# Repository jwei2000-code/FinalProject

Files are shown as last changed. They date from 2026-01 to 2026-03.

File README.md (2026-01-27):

# FinalProject
# The "Deep Work Halo"

## 1. Overview
The Deep Work Halo is a privacy-focused workspace monitor designed to help users maintain and signal a "Flow State" without distraction. It consists of a discreet wearable that analyzes head stability to detect focus levels and wirelessly updates a desktop analog gauge. This gauge visually communicates the user's cognitive state to colleagues, acting as an automatic "Do Not Disturb" signal when deep work is achieved.

## 2. Visual Concept & Physical Design

### The Sensing Device (The "Smart Ear-Cuff")
* **Form Factor:** It uses a C-bridge design. One part sits behind the ear (battery/logic), and a smaller part sits inside/front of the ear (sensor), connected by a flexible silicone bridge.
* **Physical Features:** Completely screen-less and light-less to prevent user distraction. It houses the internal electronics and battery, featuring only a single pinhole reset button on the back.

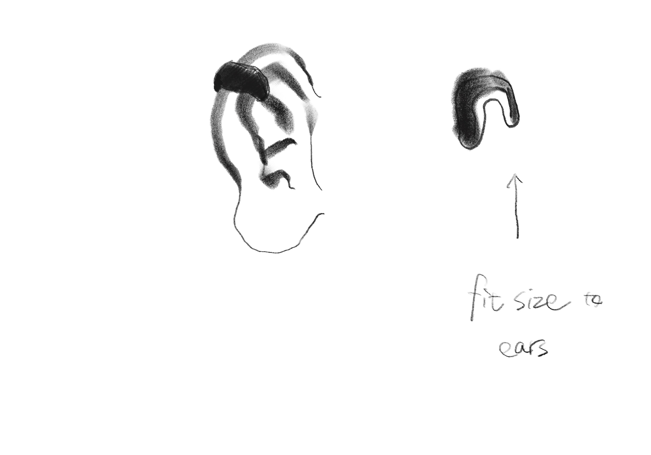
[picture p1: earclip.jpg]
Sensing Device Ear Hook


### The Display Device ("The Flow Monolith")
* **Form Factor:** A minimalist, solid cube or rectangular prism (approx. 6cm x 6cm).
* **Materials:**
    * **Inner Core:** Matte black internal chassis.
    * **Outer Shell:** Thick, frosted clear acrylic (or smoked polycarbonate) acting as a massive light diffuser.
* **The Interface (Visual):**
    * **Screen:** A hidden LED Dot Matrix (8x8 or 16x16 grids) or a low-res OLED behind the acrylic face.
    * **Typography:** Uses a strict **Bitmap / Pixel font** for a retro-futuristic aesthetic.
    * **Function:** Displays the current time by default. When focus is detected, it transitions to a "Focus Score" (0-100) or a pixelated status icon.
* **The Interface (Atmosphere):**
    * **Breathing Light:** Buried RGB LEDs illuminate the entire acrylic block from within.
    * **Behavior:**
        * *Standby:* Off or faint white (Clock Mode).
        * *Flow State:* Gently pulses in warm Amber/Red (Do Not Disturb signal).
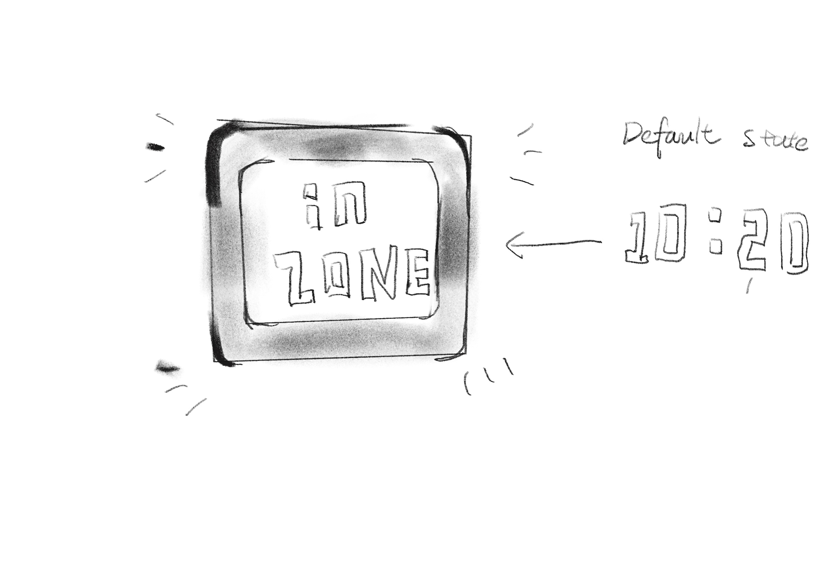
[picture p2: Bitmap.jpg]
Display Device Monolith


## 3. Technical Architecture

### Sensors & Inputs (The "Sense")
* **Device:** 6-Axis IMU (Inertial Measurement Unit).
* **Function:** Captures accelerometer and gyroscope data to track head micro-movements.
* **Logic:** A TinyML model running locally on the wearable classifies data into states (e.g., Focused vs. Fidgeting vs. Talking).

### Interface & Outputs (The "Feedback")
* **Stepper Motor:** Provides non-intrusive, peripheral visual feedback on focus depth.
* **RGB LED Ring:** Provides social signaling (Red/Amber = DND) to the external environment.

### Connectivity & Power
* **Wireless Protocol:** BLE (Bluetooth Low Energy) for efficient communication between the Wearable (Server) and Desktop Gauge (Client).
* **Power Source:**
    * *Wearable:* CR2032 Coin Cell (optimized for deep sleep).
    * *Desktop:* LiPo battery with USB-C charging.

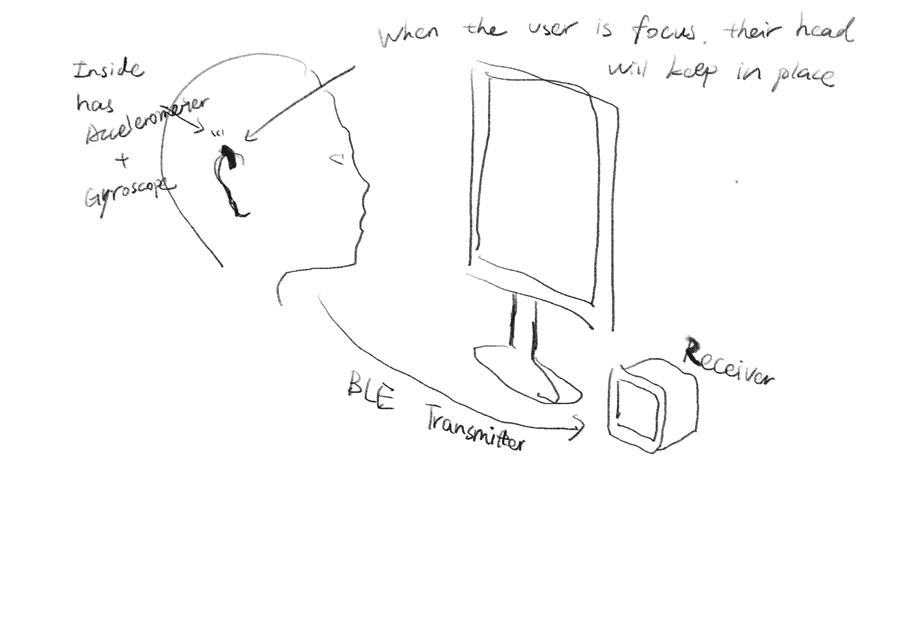
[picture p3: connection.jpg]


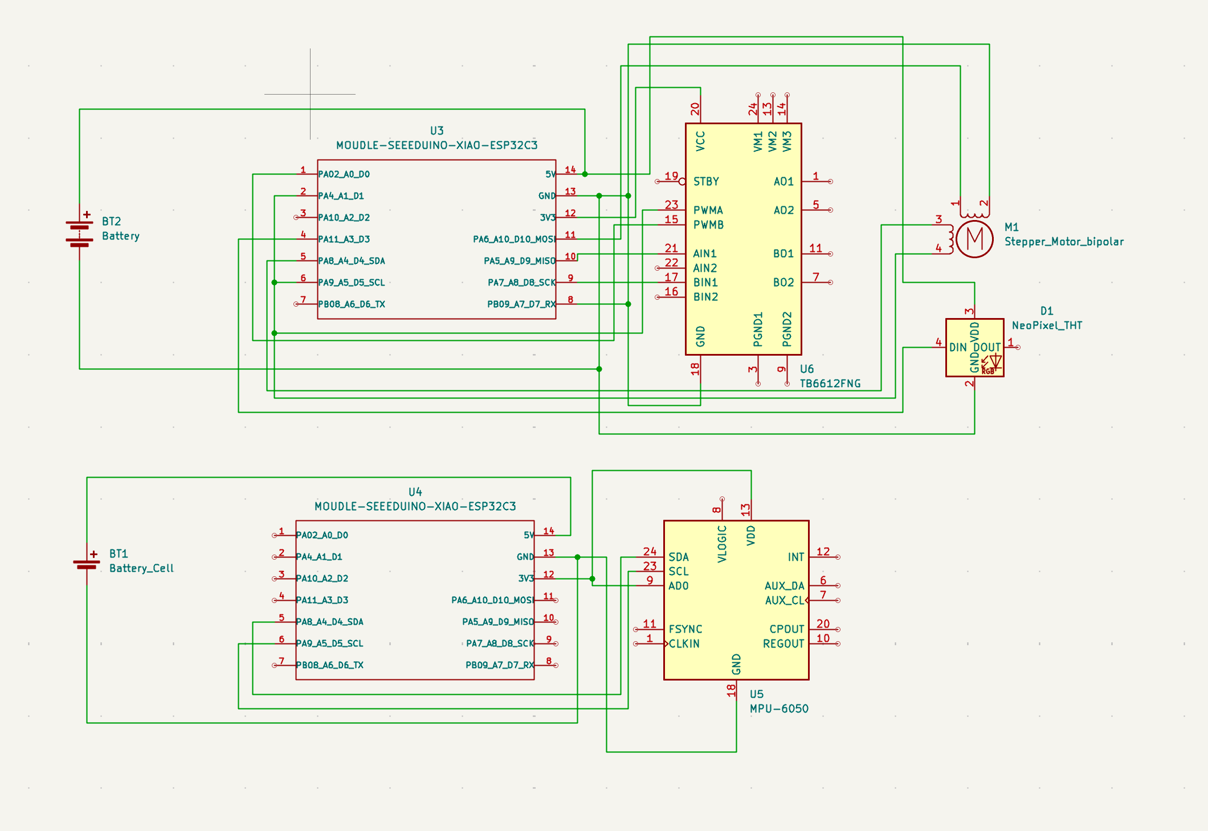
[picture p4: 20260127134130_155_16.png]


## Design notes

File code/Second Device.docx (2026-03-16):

The script uses a SwitecX25 stepper motor to physically move a needle to an "In Zone" position when my focus level hits a threshold of 70, giving me that non-intrusive peripheral feedback I wanted. At the same time, it controls a 7-bit WS2812B LED ring on pin D9 to create a "breathing" amber light effect, which serves as a social signal to tell others I’m in a deep work state. In its default state, the motor stays at a "Ready" position, and the LEDs remain off to keep my environment distraction-free.

One Photo of Functional Breadboard, Perfboard, or PCB

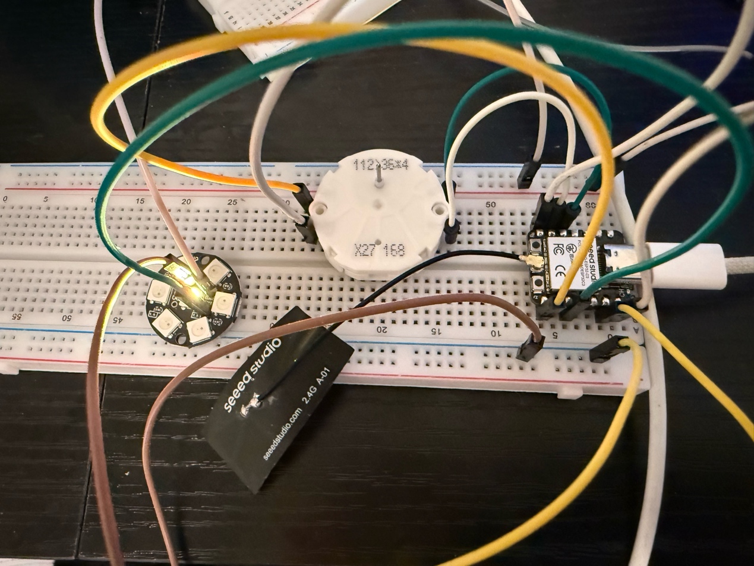
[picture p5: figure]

Two screenshots of CAD Model

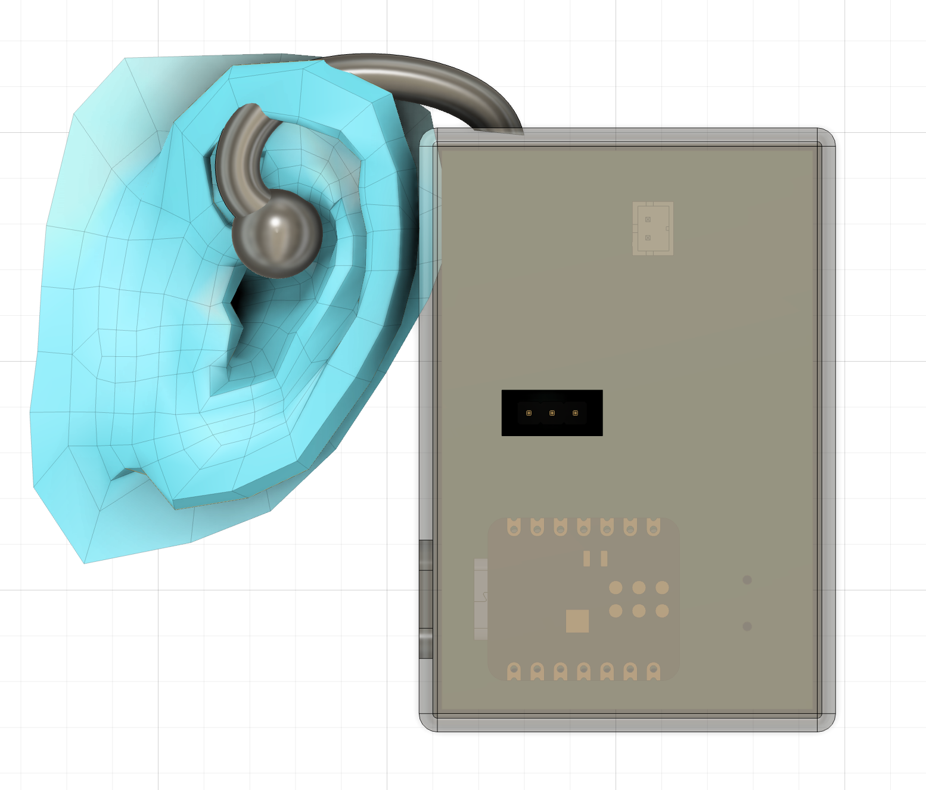
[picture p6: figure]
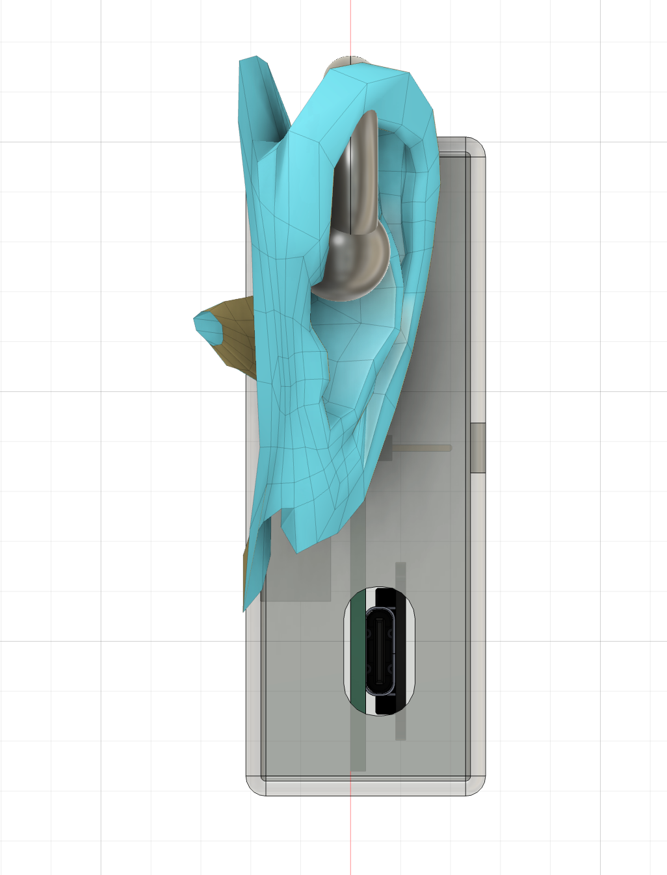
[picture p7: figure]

Link to code in Github

https://github.com/jwei2000-code/FinalProject/tree/main/code/display

#include <SwitecX25.h>

#include <Adafruit_NeoPixel.h>

#include <BLEDevice.h>

// --- Configuration ---

#define LED_PIN D9

#define NUM_LEDS 7

#define STEPS 945

#define IN_ZONE_POS 800

#define READY_POS 100

// IMPORTANT: use ESP32 GPIO numbers that you wired through a driver (ULN2003/transistors)

// XIAO ESP32C3 example pins (change to your actual wiring)

#define COIL1 4

#define COIL2 5

#define COIL3 6

#define COIL4 7

SwitecX25 motor(STEPS, COIL1, COIL2, COIL3, COIL4);

Adafruit_NeoPixel ring(NUM_LEDS, LED_PIN, NEO_GRB + NEO_KHZ800);

int focusLevel = 0;

void setup() {

Serial.begin(115200);

ring.begin();

ring.setBrightness(50);

ring.show();

motor.setPosition(READY_POS);

}

void loop() {

motor.update();

if (focusLevel >= 70) {

motor.setPosition(IN_ZONE_POS);

pulseLEDs(255, 120, 0);

} else {

motor.setPosition(READY_POS);

ring.clear();

ring.show();

}

}

void pulseLEDs(uint8_t r, uint8_t g, uint8_t b) {

float s = sin(millis() / 500.0f);

uint8_t brightness = (uint8_t)((s + 1.0f) * 127.0f);

for (int i = 0; i < NUM_LEDS; i++) {

ring.setPixelColor(i, ring.Color((r * brightness) / 255, (g * brightness) / 255, (b * brightness) / 255));

}

ring.show();

}

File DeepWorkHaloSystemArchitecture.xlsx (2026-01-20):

Wearable Sensing Device (Edge Processing) |  | Desktop Display Device (Output Controller)
Power: CR2032 Coin Cell (Deep Sleep Optimized) |  | Power: LiPo Battery / USB-C
[ 1. DATA COLLECTION ]6-Axis IMU Sensor(Accelerometer + Gyroscope)↓ |  | [ 4. RECEIVE & LOGIC ]BLE Receiver Module↓Main MCU (e.g., ESP32)(Interprets State, manages animations)↓
[ 2. TINYML INFERENCE ]Onboard Low-Power MCU(Runs Pre-trained Model: Classifies Motion vs. Stillness)↓ | → BLE → | [ 5. DUAL OUTPUT DRIVERS ]Does User = Focused?↙️ ↘️
[ 3. STATE TRANSMISSION ]BLE Transmitter(Sends simplified "State Packet" e.g., 0=Idle, 1=Flow) |  | [Output A: Info] [Output B: Mood]LED Matrix Driver PWM LED Driver↓ ↓Bitmap Display Acrylic Aura LEDs(Clock fades to Icon) ("Breathing" Light)

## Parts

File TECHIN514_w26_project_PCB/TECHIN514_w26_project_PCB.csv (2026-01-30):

Reference | Qty | Value | DNP | Exclude from BOM | Exclude from Board | Footprint | Datasheet
C1 | 1 | 0.1µF |  |  |  | Capacitor_SMD:C_0603_1608Metric_Pad1.08x0.95mm_HandSolder | ~
C2 | 1 | 4.7µF |  |  |  | Capacitor_SMD:C_0603_1608Metric_Pad1.08x0.95mm_HandSolder | ~
C3 | 1 | 0.47µF |  |  |  | Capacitor_SMD:C_0603_1608Metric_Pad1.08x0.95mm_HandSolder | ~
D1 | 1 | LED |  |  |  | LED_SMD:LED_0603_1608Metric_Pad1.05x0.95mm_HandSolder | ~
J1 | 1 | Conn_01x04_Pin |  |  |  | Connector_PinSocket_2.54mm:PinSocket_1x04_P2.54mm_Vertical | ~
R1,R2,R3 | 3 | 10kΩ |  |  |  | Resistor_SMD:R_0603_1608Metric_Pad0.98x0.95mm_HandSolder | ~
R4 | 1 | 0.45µF |  |  |  | Resistor_SMD:R_0603_1608Metric_Pad0.98x0.95mm_HandSolder | ~
R5 | 1 | 330kΩ |  |  |  | Resistor_SMD:R_0603_1608Metric_Pad0.98x0.95mm_HandSolder | ~
R6 | 1 | 698kΩ |  |  |  | Resistor_SMD:R_0603_1608Metric_Pad0.98x0.95mm_HandSolder | ~
R7 | 1 | 340kΩ |  |  |  | Resistor_SMD:R_0603_1608Metric_Pad0.98x0.95mm_HandSolder | ~
R8 | 1 | 10KΩ |  |  |  | Resistor_SMD:R_0603_1608Metric_Pad0.98x0.95mm_HandSolder | ~
U1 | 1 | LTR-390UV-01 |  |  |  | LTR_390UV_01_footprints:SMD6_LTR-390UV-01_LTO | LTR-390UV-01
U2 | 1 | ADP3331ARTZ-REEL7 |  |  |  | ADP3331ARTZ_REEL7_footprints:SOT95P280X145-6N

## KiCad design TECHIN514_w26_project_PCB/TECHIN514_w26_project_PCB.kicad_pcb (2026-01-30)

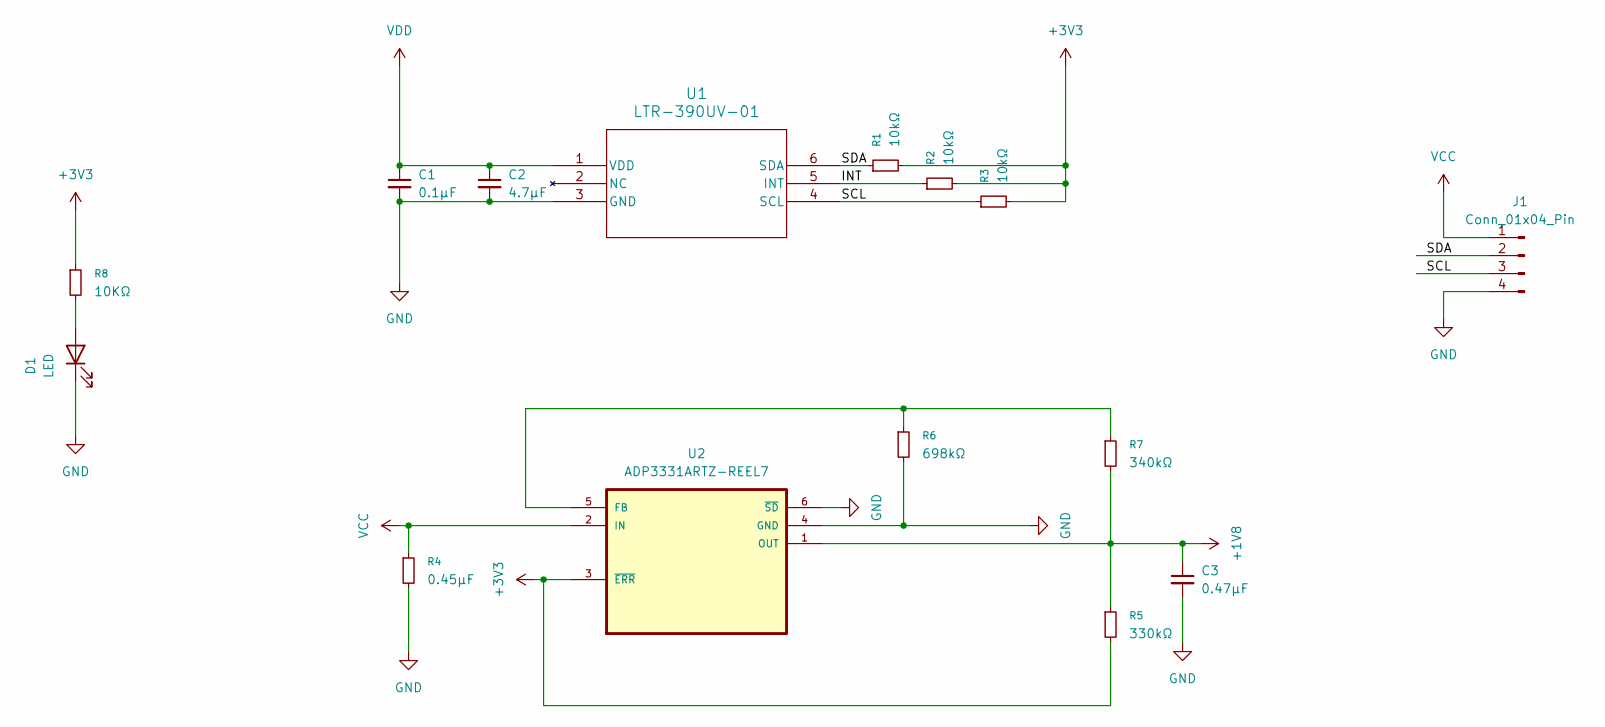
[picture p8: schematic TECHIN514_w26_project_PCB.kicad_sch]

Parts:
C1: 0.1µF; C_0603_1608Metric_Pad1.08x0.95mm_HandSolder
C2: 4.7µF; C_0603_1608Metric_Pad1.08x0.95mm_HandSolder
C3: 0.47µF; C_0603_1608Metric_Pad1.08x0.95mm_HandSolder
D1: LED; LED_0603_1608Metric_Pad1.05x0.95mm_HandSolder
J1: Conn_01x04_Pin; PinSocket_1x04_P2.54mm_Vertical
R1, R2, R3: 10kΩ; R_0603_1608Metric_Pad0.98x0.95mm_HandSolder
R4: 0.45µF; R_0603_1608Metric_Pad0.98x0.95mm_HandSolder
R5: 330kΩ; R_0603_1608Metric_Pad0.98x0.95mm_HandSolder
R6: 698kΩ; R_0603_1608Metric_Pad0.98x0.95mm_HandSolder
R7: 340kΩ; R_0603_1608Metric_Pad0.98x0.95mm_HandSolder
R8: 10KΩ; R_0603_1608Metric_Pad0.98x0.95mm_HandSolder
U1: LTR-390UV-01; SMD6_LTR-390UV-01_LTO
U2: ADP3331ARTZ-REEL7; SOT95P280X145-6N

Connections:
+1V8: C3.1, R5.1, R7.2, U2.1 (OUT)
+3V3: R1.2, R2.2, R3.2, R5.2, R8.1, U2.3 (~ERR)
/INT: R2.1, U1.5 (INT)
/SCL: J1.3, R3.1, U1.4 (SCL)
/SDA: J1.2, R1.1, U1.6 (SDA)
GND: C1.2, C2.2, C3.2, D1.1 (K), J1.4, R4.2, R6.2, U1.3 (GND), U2.4 (GND), U2.6 (~SD)
unnamed: D1.2 (A), R8.2
unnamed: R6.1, R7.1, U2.5 (FB)
VCC: J1.1, R4.1, U2.2 (IN)
VDD: C1.1, C2.1, U1.1 (VDD)

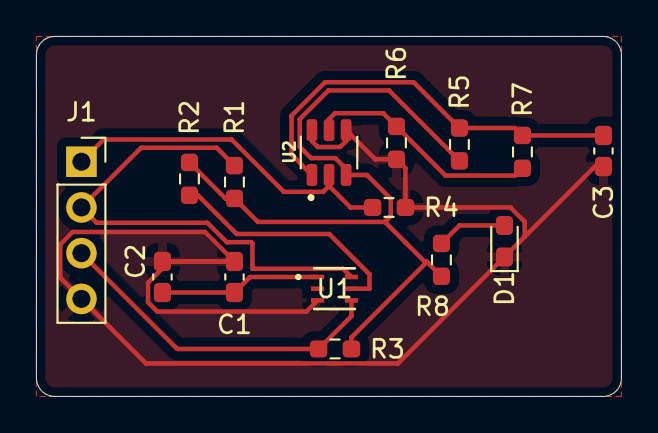
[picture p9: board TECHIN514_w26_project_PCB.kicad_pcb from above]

Board: 2 copper layers, 32.5 x 20.0 mm, 15 parts (0 on the bottom side), 10 nets.

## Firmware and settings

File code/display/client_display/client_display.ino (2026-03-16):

#include <Arduino.h>
#include <BLEDevice.h>
#include <BLEUtils.h>
#include <BLEScan.h>
#include <BLEAdvertisedDevice.h>
#include <SwitecX25.h>
#include <Adafruit_NeoPixel.h>
#include <math.h>

static BLEUUID serviceUUID("30e2772d-6dda-4baa-a391-ec111e9b1a84");
static BLEUUID    charUUID("0e26f354-8aae-46ea-9dce-195ce2227fad");

#define STEPS           630
#define NOT_FOCUSED_POS 30
#define FOCUSED_POS     600
#define COIL1 4
#define COIL2 5
#define COIL3 6
#define COIL4 7
#define LED_PIN  D9
#define NUM_LEDS 7

SwitecX25 motor(STEPS, COIL1, COIL2, COIL4, COIL3);
Adafruit_NeoPixel ring(NUM_LEDS, LED_PIN, NEO_GRB + NEO_KHZ800);

static boolean doConnect = false;
static boolean connected = false;
static BLERemoteCharacteristic* pRemoteCharacteristic;
static BLEAdvertisedDevice* myDevice;
static BLEScan* pBLEScan;

volatile int focusScore = 0;
unsigned long lastLEDUpdate = 0;
unsigned long lastScanStart = 0;
int lastMotorPos = NOT_FOCUSED_POS;

inline int clampPos(int p) { return constrain(p, 0, STEPS - 1); }

void pulseLEDs(uint8_t r, uint8_t g, uint8_t b) {
  float s = sin(millis() / 500.0f);
  uint8_t brightness = (uint8_t)((s + 1.0f) * 127.0f);
  for (int i = 0; i < NUM_LEDS; i++)
    ring.setPixelColor(i, ring.Color((r*brightness)/255, (g*brightness)/255, (b*brightness)/255));
  ring.show();
}

void solidLEDs(uint8_t r, uint8_t g, uint8_t b) {
  for (int i = 0; i < NUM_LEDS; i++)
    ring.setPixelColor(i, ring.Color(r, g, b));
  ring.show();
}

static void notifyCallback(BLERemoteCharacteristic* p, uint8_t* pData, size_t length, bool isNotify) {
  focusScore = String((char*)pData).substring(0, length).toInt();
}

class MyClientCallback : public BLEClientCallbacks {
  void onConnect(BLEClient* p) {}
  void onDisconnect(BLEClient* p) {
    connected = false;
    focusScore = 0;
  }
};

bool connectToServer() {
  BLEClient* pClient = BLEDevice::createClient();
  pClient->setClientCallbacks(new MyClientCallback());
  pClient->connect(myDevice);
  pClient->setMTU(517);
  BLERemoteService* pRemoteService = pClient->getService(serviceUUID);
  if (!pRemoteService) { pClient->disconnect(); return false; }
  pRemoteCharacteristic = pRemoteService->getCharacteristic(charUUID);
  if (!pRemoteCharacteristic) { pClient->disconnect(); return false; }
  if (pRemoteCharacteristic->canNotify())
    pRemoteCharacteristic->registerForNotify(notifyCallback);
  connected = true;
  return true;
}

class MyAdvertisedDeviceCallbacks : public BLEAdvertisedDeviceCallbacks {
  void onResult(BLEAdvertisedDevice advertisedDevice) {
    if (advertisedDevice.haveServiceUUID() && advertisedDevice.isAdvertisingService(serviceUUID)) {
      pBLEScan->stop();
      myDevice = new BLEAdvertisedDevice(advertisedDevice);
      doConnect = true;
    }
  }
};

void startScan() {
  pBLEScan->clearResults();
  pBLEScan->start(5, false);
  lastScanStart = millis();
}

void setup() {
  Serial.begin(115200);
  ring.begin(); ring.setBrightness(50); ring.clear(); ring.show();

  motor.setPosition(0);
  for (int i = 0; i < 6000; i++) { motor.update(); delayMicroseconds(800); }
  motor.setPosition(clampPos(NOT_FOCUSED_POS));
  for (int i = 0; i < 3000; i++) { motor.update(); delayMicroseconds(800); }

  BLEDevice::init("");
  pBLEScan = BLEDevice::getScan();
  pBLEScan->setAdvertisedDeviceCallbacks(new MyAdvertisedDeviceCallbacks());
  pBLEScan->setInterval(1349);
  pBLEScan->setWindow(449);
  pBLEScan->setActiveScan(true);
  startScan();
}

void loop() {
  motor.update();

  unsigned long now = millis();

  if (doConnect) {
    doConnect = false;
    if (connectToServer()) {
      Serial.println("Connected!");
    } else {
      Serial.println("Failed, retrying...");
      startScan();
    }
  }

  if (!connected && (now - lastScanStart >= 6000)) {
    startScan();
  }

  int targetPos = (focusScore >= 30) ? clampPos(FOCUSED_POS) : clampPos(NOT_FOCUSED_POS);
  if (targetPos != lastMotorPos) {
    motor.setPosition(targetPos);
    lastMotorPos = targetPos;
  }

  if (now - lastLEDUpdate >= 30) {
    lastLEDUpdate = now;
    if (focusScore >= 30) pulseLEDs(0, 255, 0);
    else solidLEDs(0, 0, 255);
  }
}

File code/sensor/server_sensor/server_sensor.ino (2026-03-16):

#include <Arduino.h>
#include <Wire.h>
#include <BLEDevice.h>
#include <BLEServer.h>
#include <BLEUtils.h>
#include <BLE2902.h>

// ── BLE UUIDs ──────────────────────────────────────────────────
#define SERVICE_UUID        "30e2772d-6dda-4baa-a391-ec111e9b1a84"
#define CHARACTERISTIC_UUID "0e26f354-8aae-46ea-9dce-195ce2227fad"

// ── MPU6500 ────────────────────────────────────────────────────
#define MPU_ADDR 0x68

// ── Moving average filter ──────────────────────────────────────
const int FILTER_SIZE = 10;
float gyroReadings[FILTER_SIZE] = {0};
int filterIndex = 0;
float filterSum = 0.0;

// ── BLE globals ────────────────────────────────────────────────
BLEServer* pServer = NULL;
BLECharacteristic* pCharacteristic = NULL;
bool deviceConnected = false;
bool oldDeviceConnected = false;

class MyServerCallbacks : public BLEServerCallbacks {
    void onConnect(BLEServer* pServer)    { deviceConnected = true;  Serial.println("Client connected!"); }
    void onDisconnect(BLEServer* pServer) { deviceConnected = false; Serial.println("Client disconnected!"); }
};

// ── MPU helpers (exactly from your working code) ───────────────
void mpuWrite(byte reg, byte val) {
  Wire.beginTransmission(MPU_ADDR);
  Wire.write(reg);
  Wire.write(val);
  Wire.endTransmission(true);
}

byte mpuRead(byte reg) {
  Wire.beginTransmission(MPU_ADDR);
  Wire.write(reg);
  Wire.endTransmission(false);
  Wire.requestFrom(MPU_ADDR, 1);
  return Wire.available() ? Wire.read() : 0xFF;
}

// ── Moving average DSP ─────────────────────────────────────────
float movingAverage(float newVal) {
  filterSum -= gyroReadings[filterIndex];
  gyroReadings[filterIndex] = newVal;
  filterSum += newVal;
  filterIndex = (filterIndex + 1) % FILTER_SIZE;
  return filterSum / FILTER_SIZE;
}

// ── Map smoothed gyro magnitude to focus score 0-100 ──────────
int calcFocusScore(float smoothedMag) {
  const float MAX_MAG = 150.0;
  return (int)(constrain(smoothedMag / MAX_MAG, 0.0, 1.0) * 100.0);
}

void setup() {
  Serial.begin(115200);
  delay(1000);  // 
  
  // ── MPU init (same as your working code) ────────────────────
  Wire.begin(6, 7);
  Wire.setClock(100000);
  delay(250);

  Serial.println("Initializing MPU6500...");
  mpuWrite(0x6B, 0x00); delay(100);
  mpuWrite(0x1C, 0x10);
  mpuWrite(0x1B, 0x08);
  mpuWrite(0x1A, 0x04);

  Serial.print("WHO_AM_I: 0x");
  Serial.println(mpuRead(0x75), HEX);
  Serial.println("MPU Init done!");

  // ── BLE init ────────────────────────────────────────────────
  BLEDevice::init("DeepWorkHalo_Sensor");
  pServer = BLEDevice::createServer();
  pServer->setCallbacks(new MyServerCallbacks());

  BLEService* pService = pServer->createService(SERVICE_UUID);
  pCharacteristic = pService->createCharacteristic(
    CHARACTERISTIC_UUID,
    BLECharacteristic::PROPERTY_READ |
    BLECharacteristic::PROPERTY_WRITE |
    BLECharacteristic::PROPERTY_NOTIFY
  );
  pCharacteristic->addDescriptor(new BLE2902());
  pCharacteristic->setValue("0");
  pService->start();

  BLEAdvertising* pAdvertising = BLEDevice::getAdvertising();
  pAdvertising->addServiceUUID(SERVICE_UUID);
  pAdvertising->setScanResponse(true);
  pAdvertising->setMinPreferred(0x06);
  pAdvertising->setMinPreferred(0x12);
  BLEDevice::startAdvertising();

  Serial.println("BLE advertising as 'DeepWorkHalo_Sensor'");
}

void loop() {
  // ── Read MPU6500 ────────────────────────────────────────────
  Wire.beginTransmission(MPU_ADDR);
  Wire.write(0x3B);
  Wire.endTransmission(false);
  Wire.requestFrom(MPU_ADDR, 14);

  if (Wire.available() < 14) {
    Serial.println("MPU read error!");
    delay(200);
    return;
  }

  int16_t ax = (Wire.read() << 8) | Wire.read();
  int16_t ay = (Wire.read() << 8) | Wire.read();
  int16_t az = (Wire.read() << 8) | Wire.read();
  int16_t rawTemp = (Wire.read() << 8) | Wire.read();
  int16_t gx = (Wire.read() << 8) | Wire.read();
  int16_t gy = (Wire.read() << 8) | Wire.read();
  int16_t gz = (Wire.read() << 8) | Wire.read();

  float accX  = ax / 4096.0;
  float accY  = ay / 4096.0;
  float accZ  = az / 4096.0;
  float gyroX = gx / 65.5;
  float gyroY = gy / 65.5;
  float gyroZ = gz / 65.5;
  float tempC = (rawTemp / 333.87) + 21.0;

  float rawMag      = sqrt(gyroX*gyroX + gyroY*gyroY + gyroZ*gyroZ);
  float smoothedMag = movingAverage(rawMag);
  int   focusScore  = calcFocusScore(smoothedMag);

  // Print same format as your working code + DSP info
  Serial.print("Acc(g): ");
  Serial.print(accX, 3); Serial.print(", ");
  Serial.print(accY, 3); Serial.print(", ");
  Serial.print(accZ, 3);
  Serial.print("  |  Gyro(°/s): ");
  Serial.print(gyroX, 2); Serial.print(", ");
  Serial.print(gyroY, 2); Serial.print(", ");
  Serial.print(gyroZ, 2);
  Serial.print("  |  Temp: ");
  Serial.print(tempC, 1); Serial.print("°C");
  Serial.print("  |  RawMag: ");   Serial.print(rawMag, 2);
  Serial.print("  |  Smoothed: "); Serial.print(smoothedMag, 2);
  Serial.print("  |  Score: ");    Serial.println(focusScore);

  // ── Transmit over BLE ────────────────────────────────────────
  if (deviceConnected) {
    String val = String(focusScore);
    pCharacteristic->setValue(val.c_str());
    pCharacteristic->notify();
  }

  // ── Reconnect handling ───────────────────────────────────────
  if (!deviceConnected && oldDeviceConnected) {
    delay(500);
    pServer->startAdvertising();
    Serial.println("Restarting advertising...");
    oldDeviceConnected = deviceConnected;
  }
  if (deviceConnected && !oldDeviceConnected) {
    oldDeviceConnected = deviceConnected;
  }

  delay(200);
}
